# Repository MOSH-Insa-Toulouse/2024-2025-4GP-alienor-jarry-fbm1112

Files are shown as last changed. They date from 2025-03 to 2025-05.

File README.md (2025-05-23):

# 2024-2025-4GP - Projet Capteur low-tech Graphite - Aliénor Jarry et Bastien Maïs

## Sommaire :
- [Contexte](#contexte)
- [Livrables](#livrables)
- [Matériel nécessaire](#matériel-nécessaire)
- [1. Simulation électronique du capteur sous LTSpice](#1-simulation-électronique-du-capteur-sous-ltspice)
- [2. Design du PCB sous KiCad](#2-design-du-pcb-sous-kicad)
- [3. Réalisation du Shield](#3-réalisation-du-shield)
- [4. Code Arduino](#4-code-arduino)
- [5. Application Android APK sous MIT App Inventor](#5-application-android-apk-sous-mit-app-inventor)
- [6. Banc de test](#6-banc-de-test)
- [7. Datasheet du capteur](#7-datasheet-du-capteur)
- [Conclusion](#conclusion)
- [Contacts](#contacts)

## Contexte
Dans le cadre de l'UF "Du capteur au banc de test en open source hardware" se déroulant lors de notre 4ème année Génie Physique à l'INSA de Toulouse, nous avons développé un capteur à jauge de contrainte low-tech à base de crayon graphite. Ce projet repose sur le rapport scientifique "Pencil Drawn Strain Gauges and Chemiresistors on Paper", publié en 2014 par Cheng-Wei Lin*, Zhibo Zhao*, Jaemyung Kim & Jiaxing Huang.

Le capteur se compose uniquement d'un morceau de papier sur laquelle une trace de crayon à papier dépose une fine couche de graphite. Un dépôt de graphite sur du papier constitue un système granulaire, où des grains de tailles variables sont séparés par une distance appelée distance inter-grain. La conductance suit une loi exponentielle décroissante en fonction de la distance inter-grain, laquelle peut être modifiée en déformant le papier. Plus la distance inter-grain augmente, plus la conductance diminue. Dans ce cas, la résistance devient très élevée, car conductance et résistance sont inversement proportionnelles. Ainsi, la contrainte exercée sur le matériau peut être déterminée en mesurant simplement la résistance aux bornes du capteur.

L'objectif est de concevoir un dispositif permettant la mesure de déformation à partir d'un capteur low-tech, puis d'évaluer ses performances en le comparant à un capteur commercial.

## Livrables
- Un Shield PCB branchée sur une carte Arduino UNO, intégrant un capteur graphite, un amplificateur de transimpédance et un module Bluetooth. Idéalement, il incluerait également un écran OLED, un encodeur rotatif, un potentiomètre numérique (remplaçant la résistance R2 dans le circuit amplificateur), ainsi qu'un connecteur pour un servomoteur et un capteur de flexion (afin de comparer ses mesures avec celles du capteur en graphite).
- Un code Arduino garantissant la gestion de tous les composants et l'acquisition des mesures (mesures de contrainte, échanges via Bluetooth, affichage OLED, encodeur rotatif, potentiomètre numérique et servomoteur).
- Une application APK Android qui gère l'interface entre le PCB et le code Arduino. L'application doit au minimum afficher la valeur de la résistance de la jauge de contrainte ainsi que sa variation relative sur le smartphone.
- Un code Arduino dédié au banc de test pour la mesure de la jauge de contrainte.
- Une datasheet du capteur en graphite (incluant le circuit de transimpédance).

## Matériel nécessaire
Pour concevoir notre dispositif électronique, voici la liste des composants nécessaires :
- Des résistances : 1 de 1 kΩ, 1 de 10 kΩ, 2 de 100 kΩ pour l'amplificateur transimpédance. 1 de 47 kΩ pour le flex sensor (capteur commercial)
- Des condensateurs : 2 de 100 nF et 1 de 1 μF pour l'amplificateur transimpédance. 1 de 100 nF pour l'encodeur rotatif
- Un amplificateur opérationnel LTC1050
- Un potentiomère numérique MCP41050
- Une carte Arduino UNO
- Un module Bluetooth HC05
- Un écran OLED 128×64
- Un encodeur rotatif
- Un servomoteur
- Un flex sensor
- Un morceau de papier et crayon pour la fabrication du capteur graphite

## 1. Simulation électronique du capteur sous LTSpice

Notre capteur graphite présente une résistance variable de l’ordre du gigaohm (GΩ). Lorsque une tension de 5V est appliquée à ses bornes, un courant extrêmement faible est généré, de l’ordre de 100 nA en moyenne.

Un tel signal est difficilement exploitable sans amplification. Pour y remédier, nous avons utilisé un montage transimpédance basé sur un amplificateur opérationnel (AOP). Ce montage permet de convertir ce courant en une tension suffisamment élevée pour être lue par le convertisseur analogique-numérique (ADC) d’une carte Arduino UNO. 

**Nous avons simulé ce montage à l’aide du logiciel LTspice, voici notre schéma du circuit analogique** : 
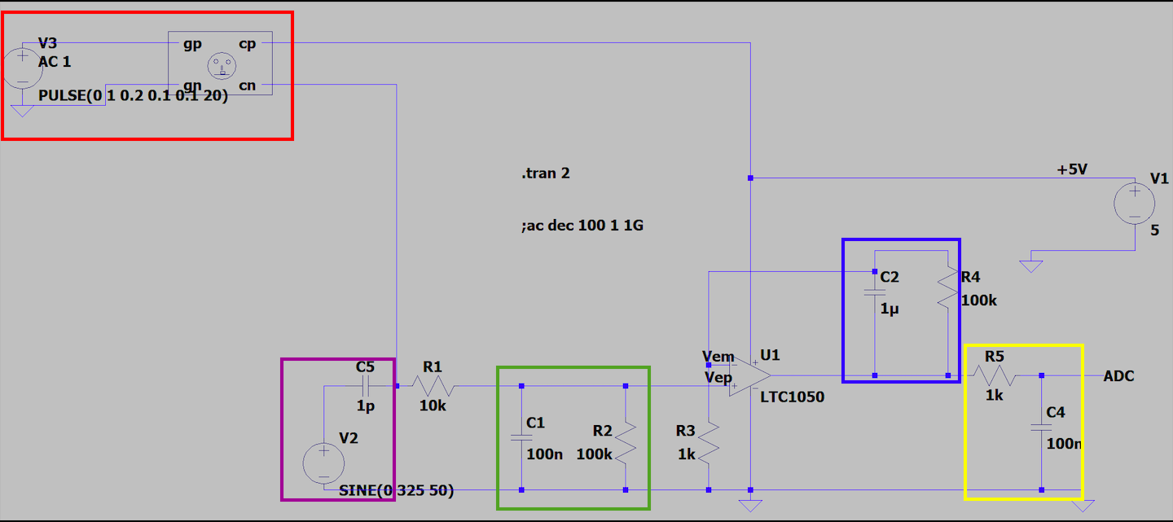
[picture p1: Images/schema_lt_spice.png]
Schéma LTSpice


Nous avons choisi l'AOP LTC1050 car il est adapté pour traiter de très faibles courants d'entrée. Son faible offset de tension assure une conversion précise du courant en tension.

**Deux éléments de simulation sont intégrés au circuit** :

- 🟥 Simulation du capteur  
- 🟪 Simulation du bruit

De plus, des filtres ont été ajoutés au montage afin d'atténuer les perturbations indésirables (par ex : bruits d'alimentation à 50 Hz) 

**Trois filtres assurant le traitement du signal** :

- 🟩 Filtre en entrée de l'AOP(R2, C1) :  
 C'est un filtre passe-bas passif de fréquence de coupure fc = 16 Hz. Il filtre les bruits en courant sur le signal d'entrée.

- 🟦Filtre couplé à l'AOP (R4, C2) :  
  C'est un filtre passe-bas actif avec fc = 1,6 Hz. Il filtre la composante du bruit à 50Hz du réseau électrique.

- 🟨 Filtre en sortie de l'AOP (R5, C4) :  
  C'est un filtre passe-bas passif avec fc = 1,6 kHz. Il élimine les parasites générés lors du traitement du signal.

De plus, la résistance R1 en entrée protège contre les décharges électrostatiques. Cette résistance en combinaison avec la capacité C5, forme un filtre pour atténuer les bruits de tension. 

**Voici la réponse de notre circuit afin de vérifier que le capteur est bien amplifié** :
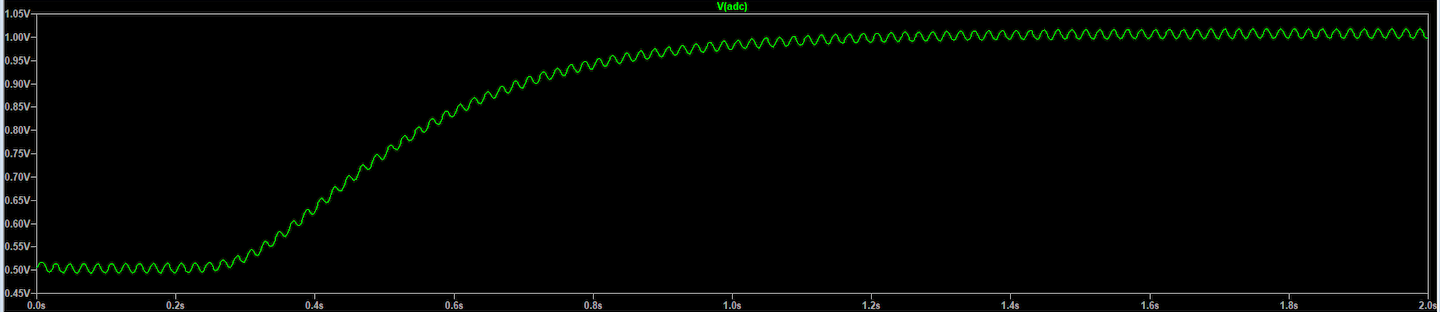
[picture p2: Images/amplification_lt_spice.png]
Réponse amplification LTSpice

Nous voyons que le signal est amplifié à 1V. Ainsi, l'Arduino UNO pourra le mesurer. 

**Réponse avec un courant alternatif pour vérifier que le bruit est bien filtré** :
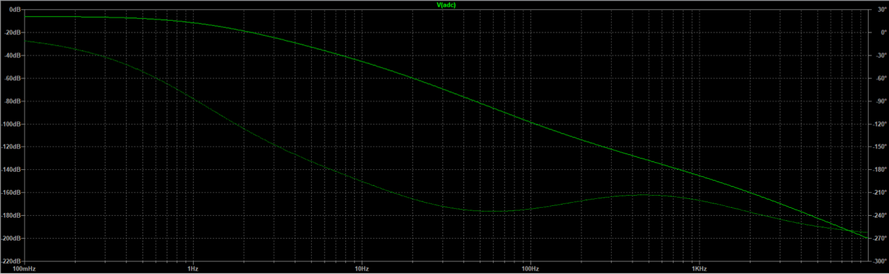
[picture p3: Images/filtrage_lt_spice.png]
Réponse filtrage LTSpice

Nous remarquons que le bruit est bien atténué à 50 Hz, d'environ 72 dB.

## 2. Design du PCB sous KiCad

Notre PCB a été conçue sur le logigiel Kicad (version 9).

Nous avons tout d'abord réalisé la schématique en reproduisant le circuit transimpédance (en enlevant la partie simulant le bruit). Nous avons  remplacé la résistance R3 par un potentiomètre digital. Cela nous permet d'ajuster le gain de notre AOP en fonctions de nos besoins. Également, nous avons créé les symboles des différents composants/modules intégrés. Ces modules assureront une mesure précise de notre capteur en graphite et permettra de comparer les résultats obtenus.

**Voici le schéma électrique de l'ensemble de notre montage** :
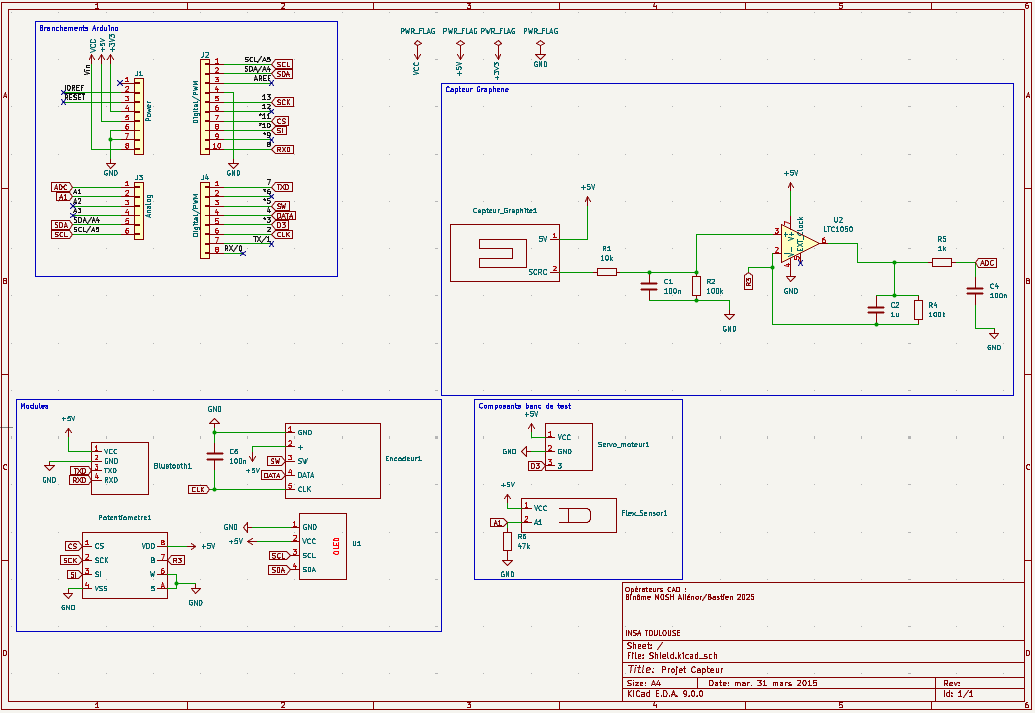
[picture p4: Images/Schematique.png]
Schematique


Ensuite, nous avons réalisé les empreintes de nos composants en prenant en compte leurs caractéristiques techniques : nombre de pins, espacement, dimensions, géométrie,...
afin de les placer sur notre PCB. 

Puis, nous sommes allés dans l'onglet "éditeur de PCB" sous Kicad pour designer notre circuit. Nous nous sommes appuyés sur un modèle de carte Arduino Uno. Nous avons ainsi placé nos différents composants, de manière à regouper les composants du circuit transmpédance. De plus les modules, et les composants du circuit transimpédance devaient être placés proches de leurs branchements Arduino respectifs. Nous sommes ensuite passés à la partie routage du circuit. Notre principale difficulté a été d’optimiser le placement des composants afin de limiter au maximum l’utilisation de vias, notamment pour les connexions au GND. Nous avons tout de même trois vias sur notre PCB. Pour garantir une bonne connexion entre toutes les broches GND des composants, nous avons mis en place un plan de masse.

**Voici le résultat final obtenu de notre routage** : 
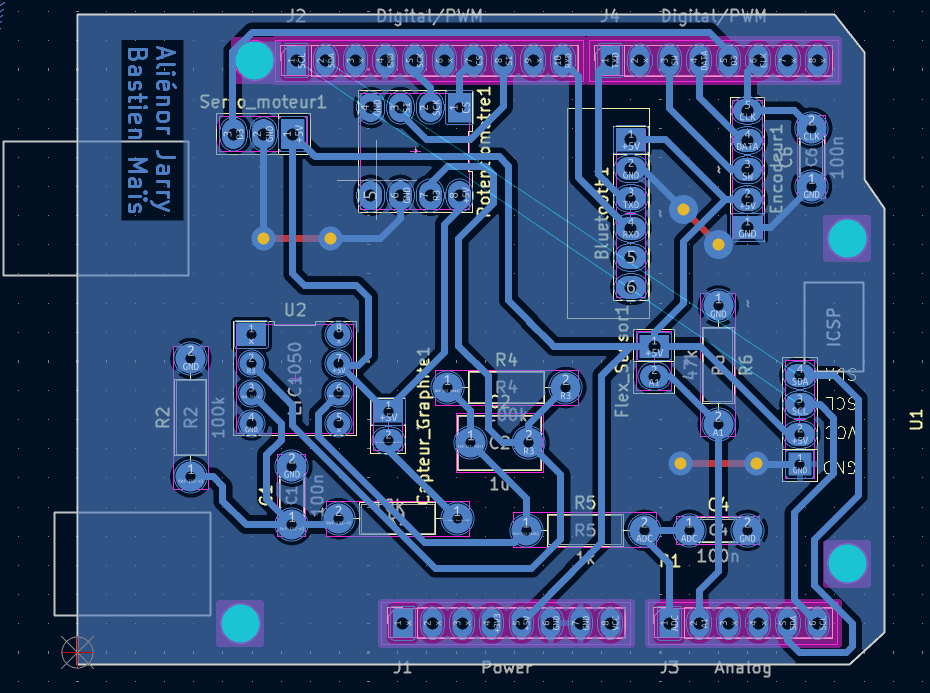
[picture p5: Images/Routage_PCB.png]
Routage_PCB


**Voici le rendu 3D de notre PCB, avec ses différents modules et composants intégrés**:
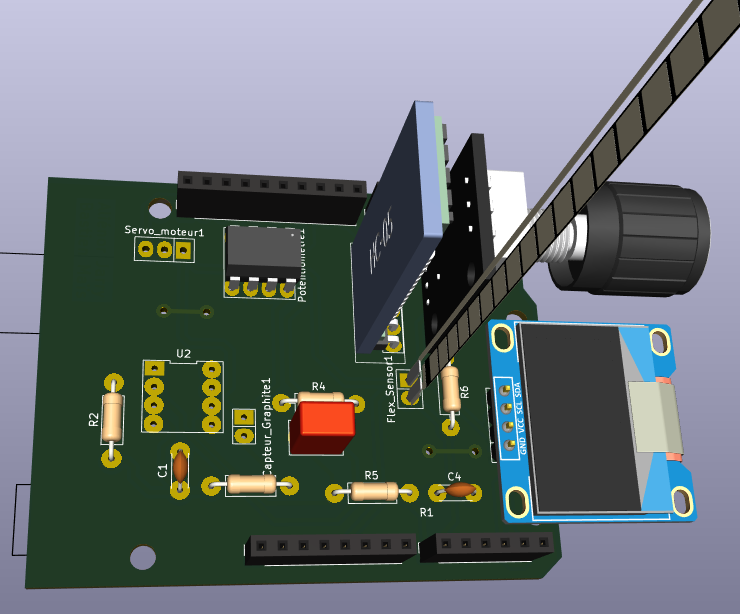
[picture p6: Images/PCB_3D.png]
PCB_3D


### **Erreurs réalisées** : 

Nous avons fait quelques erreurs concernant les empreintes de nos modules.

**Servomoteur** :
Nous avons inversé les broches GND et 5V. 

**Bluetooth HC-05** : 
L'empreinte de notre Bluetooth n'est pas correcte. Nous avions mis dans l'ordre la broche VCC, GND, TX, RX, ENABLE et STATE alors que la broche ENABLE est la première. Voici les broches correctes du Bluetooth :

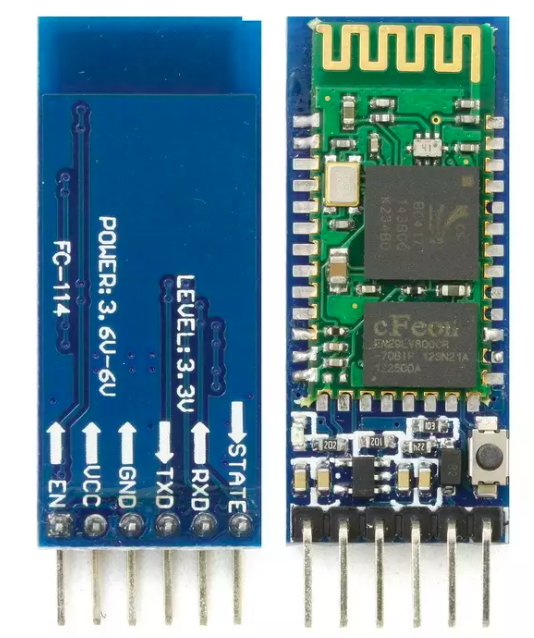
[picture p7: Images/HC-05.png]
HC-05


Un conseil serait de se baser sur la datasheet de chaques composant afin de réaliser les empreintes! De plus, il faut faire attention concerant les broches TX et RX du Bluetooth. La broche RX de la carte Arduino doit être raccordée à la broche TX du Bluetooth, et la broche TX du Arduino à la broche RX du Bluetooth.
Nous avons résolu le problème des pins Bluetooth en utilisant des connecteur mâles, femelles permettant de brancher correctement le Bluetooth.

## 3. Réalisation du Shield 

Une fois notre PCB finalisé sous KiCad, nous l’avons envoyé à Cathy afin qu’elle puisse vérifier que le PCB était conforme et prêt pour une impression correcte. Puis, nous avons généré le masque de gravure de notre PCB que Cathy s’est chargée d’imprimer. Ensuite, nous sommes allées avec Cathy au GEI afin de tirer notre PCB.

Nous n’avons pas pu manipuler directement, mais nous avons tout de même pu observer le processus de fabrication de la carte. Cathy a procédé ainsi :

1. Insolation UV de la plaque en époxy recouverte d'une fine couche de cuivre (destinée à recevoir le circuit imprimé) et d'une résine photosensible, à travers le masque, pour durcir la résine dans les zones exposées.
2. Développement : la plaque est plongée dans un révélateur pour éliminer la résine non exposée à la lumière UV, laissant ainsi un motif de résine durcie correspondant au circuit imprimé.
3. Gravure : La plaque est ensuite immergée dans un bain de perchlorure de fer, qui dissout le cuivre non protégé par la résine durcie, formant ainsi les pistes du circuit imprimé.
4. Nettoyage à l’acétone pour éliminer les résidus de résine restants après la gravure.

**Voici une photo du masque de gravure et une photo de notre PCB une fois imprimé** :
<p align="center">
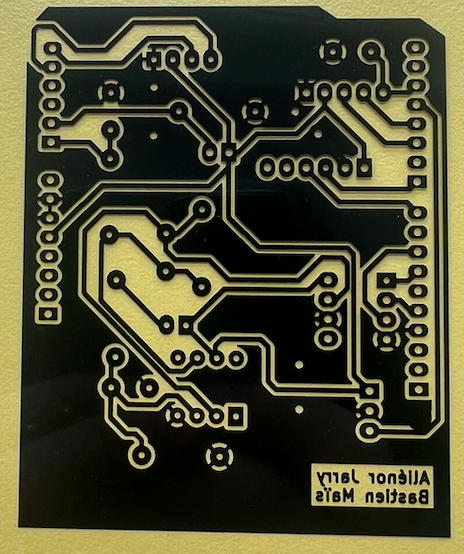
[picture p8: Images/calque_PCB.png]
calque_PCB
  
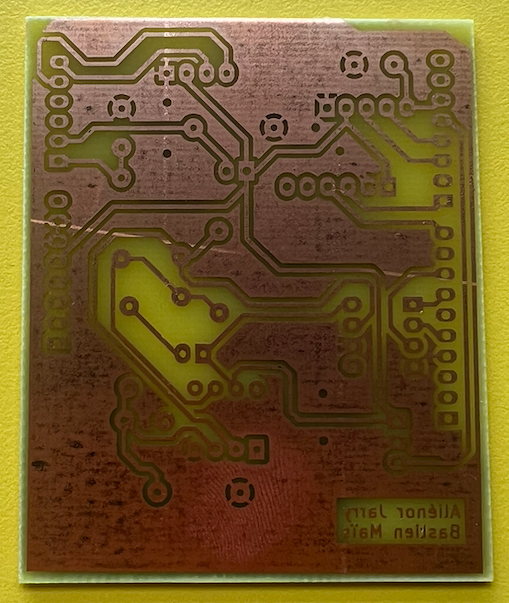
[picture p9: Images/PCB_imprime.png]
PCB_imprime
  
</p>

**Nous tenions à grandement remercier Cathy pour son aide tout au long du projet, et en particulier pour l'impression de notre PCB.**

### Assemblage du circuit :

Nous avons ensuite procédé au perçage de la plaquette pour permettre l'insertion des différents composants, en veillant à respecter la taille des trous. Un forêt plus petit était nécessaire pour les résistances et les condensateurs. Une fois le perçage effectué, nous avons soudé les composants sur le PCB. Il faut bien faire attention à souder uniquement sur les pastilles, sauf pour les pastilles GND où un débordement est moins problématique, car elles sont toutes reliées au plan de masse. Un excès de soudure sur les pastilles pourrait en effet créer des courts-circuits. De plus, nous avons dû ajouter un fil reliant la broche 5V du flex sensor au 5V du module Bluetooth, car une portion de cuivre sur la piste les reliant a été retirée accidentellement en tentant d’enlever un surplus de soudure.

**Voici une photo de l'assemblage de notre circuit (sans les modules) ainsi qu'une photo de nos soudures** :
<p align="center">
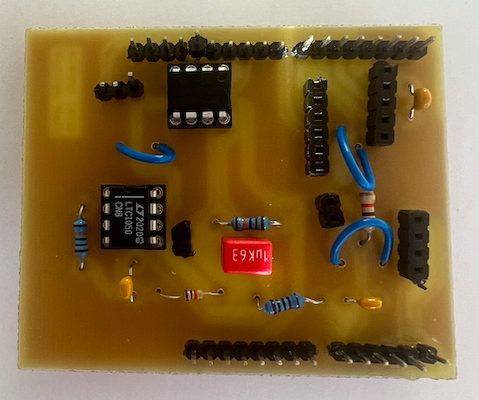
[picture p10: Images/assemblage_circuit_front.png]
assemblage_PCB
  
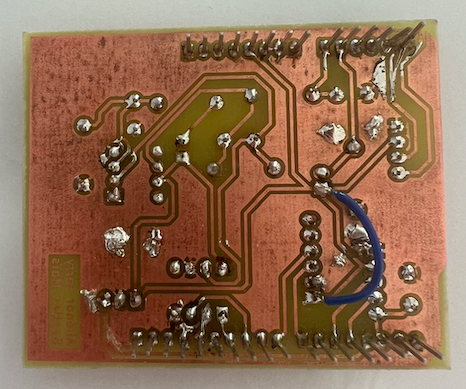
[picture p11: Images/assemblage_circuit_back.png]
soudure
  
</p>

## 4. Code Arduino 

Afin de réaliser le code arduino nous avons utilisé l'IDE 2.3.2.

Dans le cadre d'une utilisation d'application mobile nous avons donc utilisé un module bluetooth. Cela a ainsi nécessité d'inclure la librairie SoftwareSerial pour initier la communication entre l'application et le pcb via le module.

Pour une utilisation plus classique de notre montage, l'écran OLED permet l'affichage des valeurs issues des mesures de capteurs de la plaquette impliquant l'utilisation de la librairie Adafruit_SSD1306. Cette librairie est plus délicate à manipuler car gourmande en mémoire RAM. Pour pallier cet effet, il nous est impératif de limiter l'affichage au strict nécessaire afin de contrôler l'utilisation de la RAM et d'éviter d'éventuels disfonctionnements du programme.

Dans le dossier Arduino se trouve le programme complet strucuré qui permet de faire différents types de mesures selon le capteur utilisé (graphite ou flex sensor). Lors du lancement de l'Arduino, le programme effectue une calibration du potentiomètre digital selon la valeur mesurée par le capteur graphite pour ensuite afficher un menu déroulant que l'on peut balayer à l'aide de l'encodeur rotatif.

Le menu affiche 3 choix d'actions possibles : 

- Une mesure instantanée du capteur graphite toutes les 500ms
- Une mesure du flex sensor toutes les 500ms
- Une calibration du potentiomètre digital

<p align="center">
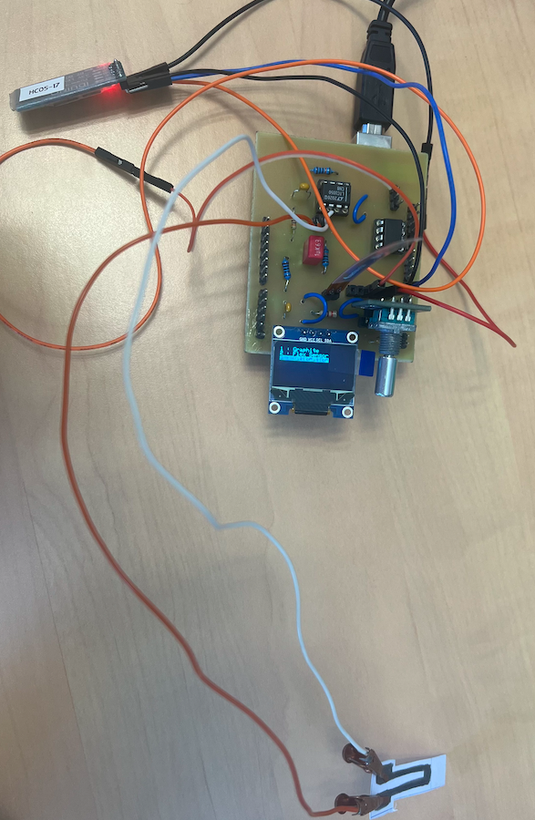
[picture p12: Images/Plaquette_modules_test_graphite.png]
Plaquette_modules
  
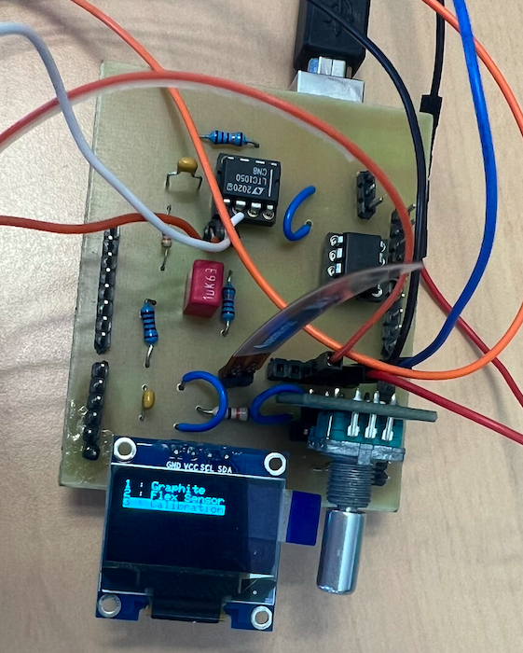
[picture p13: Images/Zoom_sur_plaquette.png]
zoom_plaquette
  
</p>

Pour sélectionner une action du menu, il suffit de tourner la molette et d'appuyer sur le bouton central de l'encodeur. Si l'on souhaite sortir d'une action du menu, nous tournons simplement la molette de l'encodeur.

Ainsi, on obtient la résistance du capteur graphite avec la formule suivante :

res

Et dans notre cas, notre résistance R3 est variable : elle est issue du réglage du potentiomètre à l'aide d'une méthode de dichotomie.

Finalement, nous n'avons pas utilisé le servomoteur comme module par manque de temps.

## 5. Application Android APK sous MIT App Inventor
Comme mentionné dans la partie précèdente, une application mobile a été réalisée sous MIT App Inventor.
L'application reçoit les données transmis par le module bluetooth HC-05 puis affiche la valeur reçue en Mohm pour le capteur graphite ou en ohms pour le flex sensor.

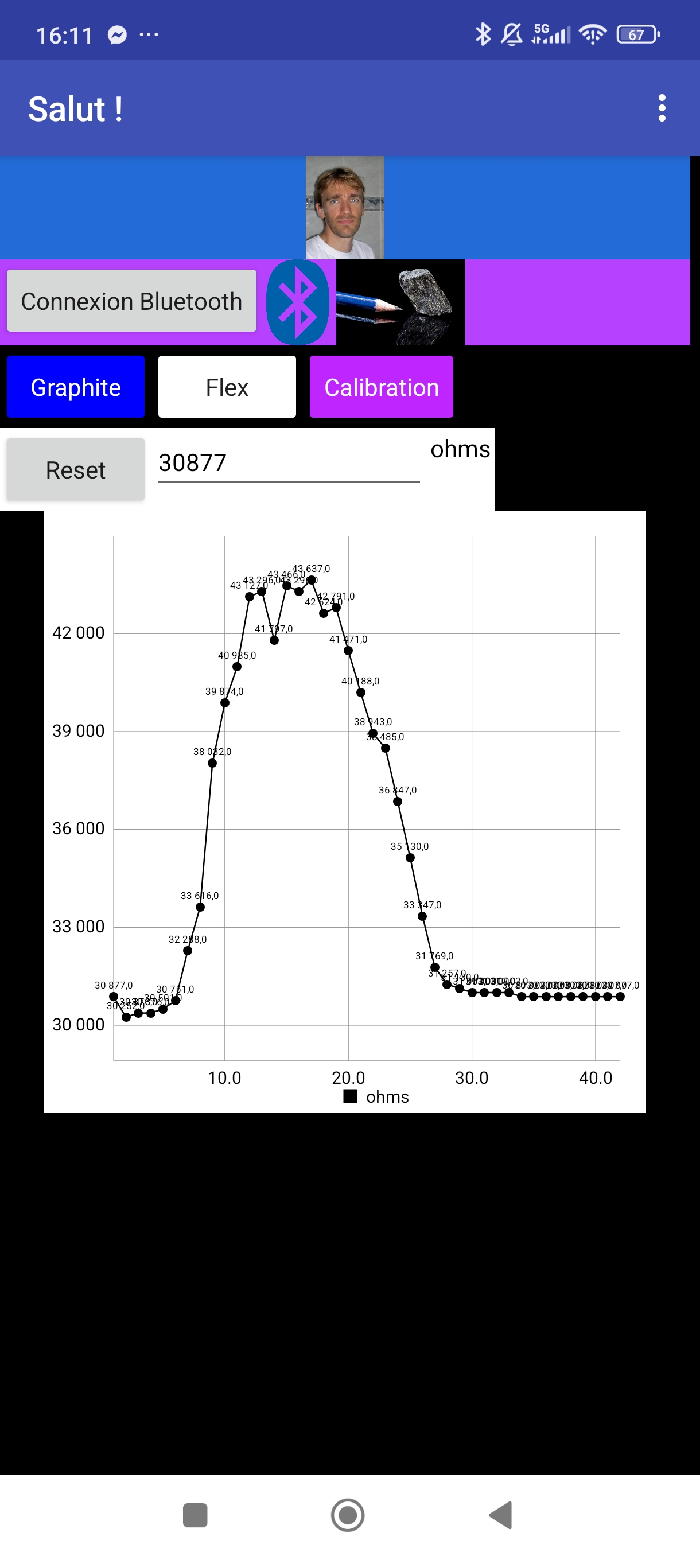
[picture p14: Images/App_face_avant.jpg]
face


<p align="center">
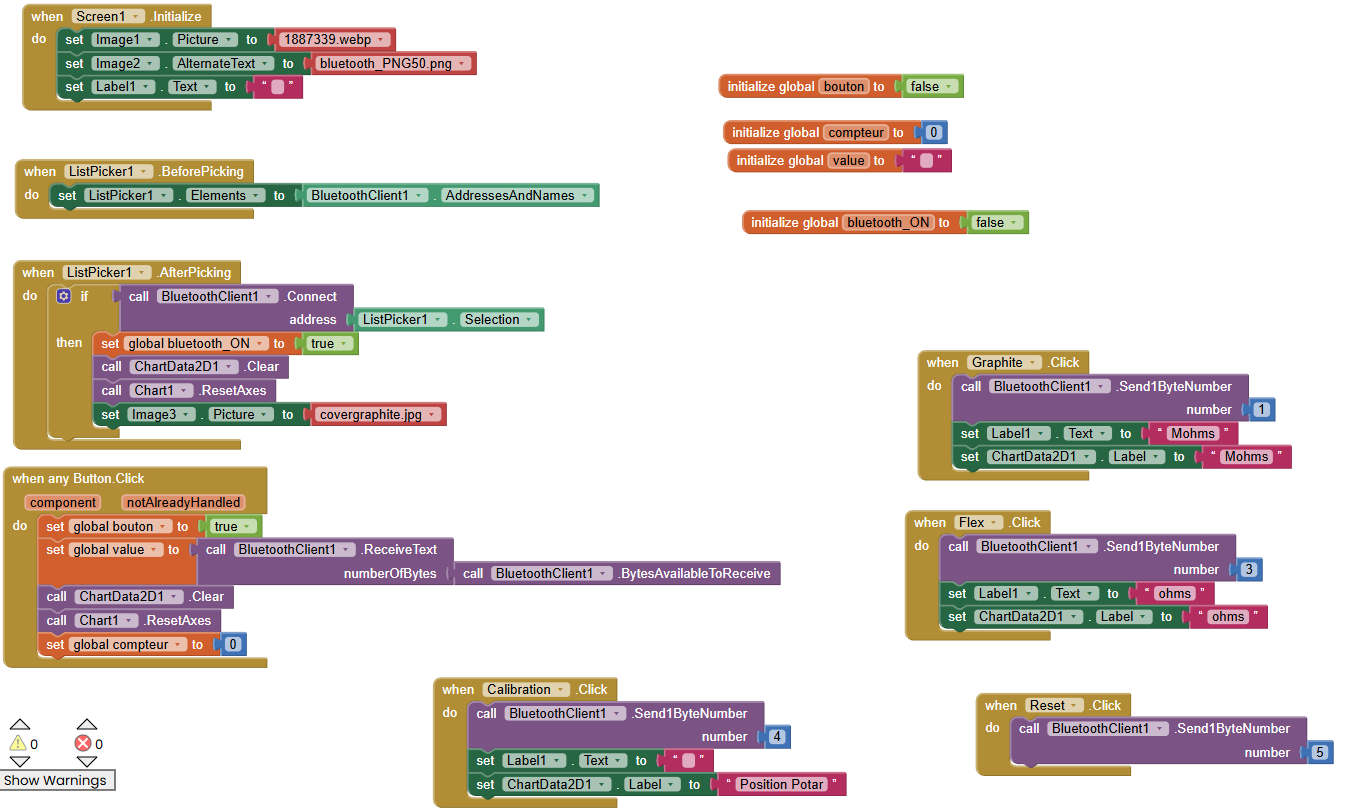
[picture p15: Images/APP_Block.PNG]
Block
  
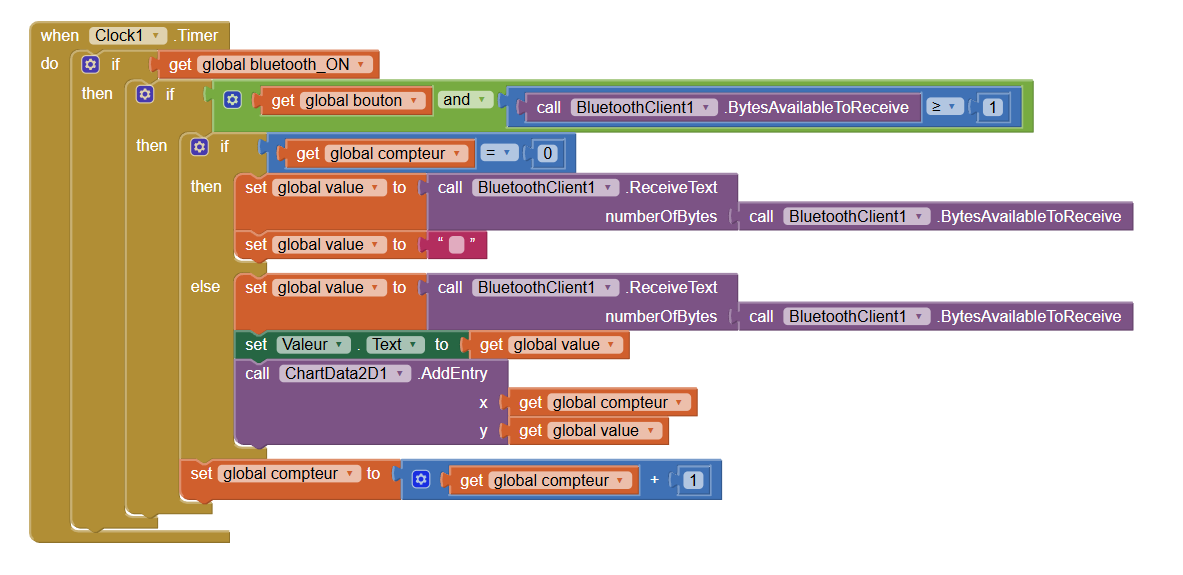
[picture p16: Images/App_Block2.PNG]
Block2
  
</p>

## 6. Banc de test
Pour spécifier notre capteur graphite et son montage transimpédance, nous avons utilisé le banc de test fabriqué par le binôme Maëlys et Arthur. Un grand merci à eux de nous avoir prêter leur banc de test. Ce banc de test comporte des demis-cercles avec des diamètres différents allant de 2cm à 4,5cm avec un rajout de 0,5cm entre chaque demi-cercle. Au total, il y a 6 demi-cercles. Ce banc de test comporte des encoches pour chaque demi-cercle qui permet d'insérer facilement le capteur. Une fois le capteur mis dans l'une de ses encoches, il est plus aisé d'appliquer une flexion ou une compression sur le capteur. La capteur se déforme en suivant la courbure du demi-cercle. Ainsi, nous appliquons une contrainte qui provoque une variation de la résistance du capteur. Nous allons mesurer cette contrainte en fonction de la déformation.

La variation relative de la résistance se définit par : ΔR/R0 (avec R0 la résistance initiale du capteur avant sa déformation et ΔR la variation de la résistance après et avant déformation). La déformation est : ε=e/D (avec e=0,2mm l'épaisseur du papier utilisé et D le diamètre du demi-cercle). Nous avons donc une déformation variant de 0.004 pour le plus grand demi-cerle à 0.01 pour le plus petit. Il faut faire attention à bien mettre les diamètres des demi-cercles en mm! 

**Voici le banc de test que nous avons utilisé :**

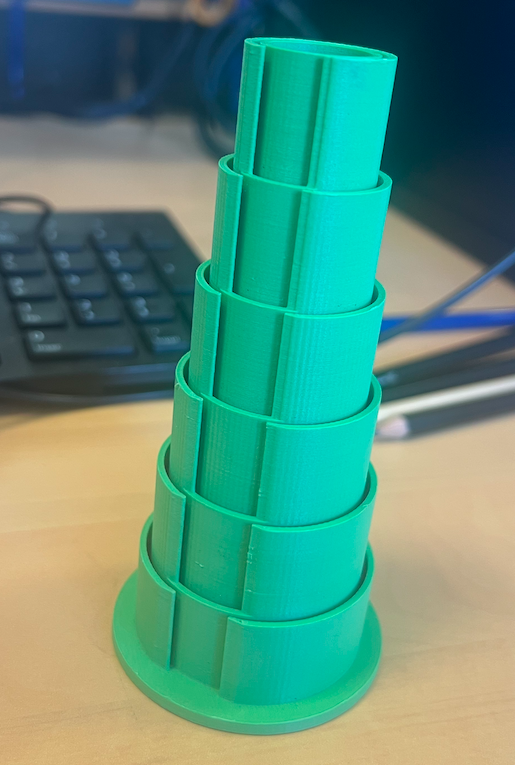
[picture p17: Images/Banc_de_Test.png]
Banc_de_Test


### Voici les courbes caractéristiques pour des crayons F, HB et B en flexion et en compression :
<p align="center">
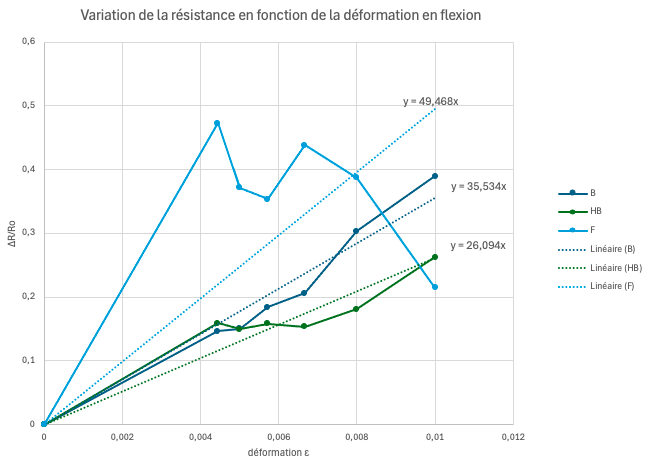
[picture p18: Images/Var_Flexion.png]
Var_Flexion
  
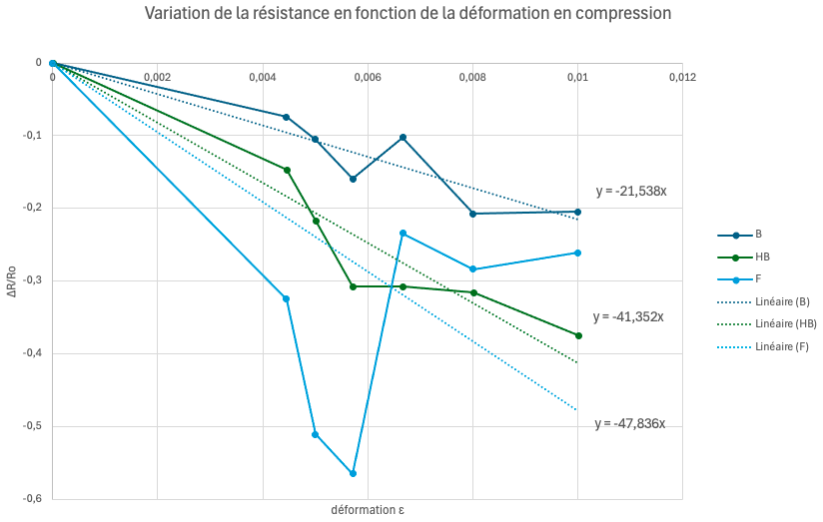
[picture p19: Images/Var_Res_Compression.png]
Var_Res_Compression
  
</p>

### Voici le graphe comparant le Flex Sensor et le capteur Graphite pour F, HB et B (en flexion) :
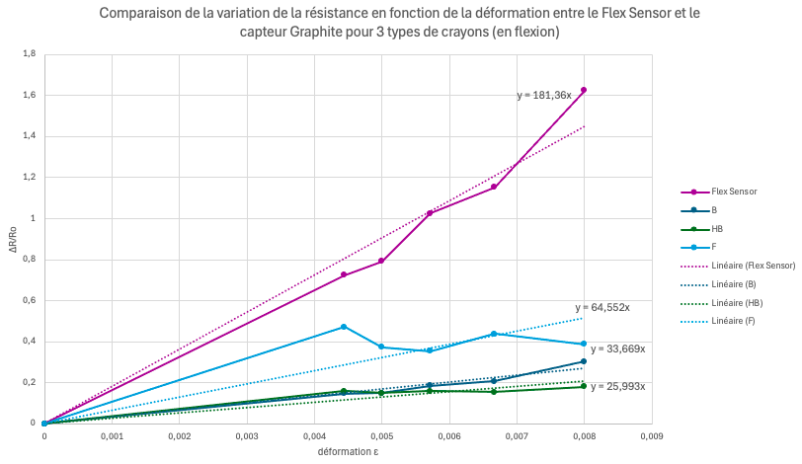
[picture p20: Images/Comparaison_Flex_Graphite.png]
Comparaison_Flex_Graphite


**Interprétation des courbes et comparaison avec la théorie :**

Nous remarquons que la résistance augmente lorsque nous mettons le capteur en flexion et que la résistance diminue lors de la compression de ce dernier. Ce phénomène est tout à fait attendu : en théorie, lorsqu’on soumet le capteur à une flexion, la monocouche de graphite déposée sur le papier s’étire, augmentant la distance entre les atomes de carbone. Cette augmentation de distance entraîne une hausse de la résistance du capteur. À l’inverse, en compression, les atomes de carbone se rapprochent, entraînant une diminution de la résistance.

Nous remarquons que les variations relatives ne sont pas les mêmes en fonction de la dureté du crayon utilisé. 
Plus le crayon est gras :  9H<...<3H<2H<H<F<HB<B<2B<3B<...9B, moins sa variation relative de résistance est élevée.
Dans notre cas, le crayon le plus dur et le crayon de type F et le plus gras est celui de type B. 
Cette théorie est vérifiée pour le cas des courbes en compression. Nous voyons bien que le type F a la variation relative la plus élevée et le B, la variation la moins élevée.
Pour le cas des courbes en flexion, la théorie n'est pas totalement vérifiée car le type F a bien la variation de résistance la plus élevée. Cependant, la variation relative la moins élevée est le type HB, alors que cela devrait être le type B. De plus, nous remarquons que nos courbes F, aussi bien en flexion qu'en compression présente un comportement non linéaire marqué. Ces courbes montrent plusieurs irrégularités et pics contrairement aux courbes de type B et HB qui sont plus linéaires.

Ces erreurs expérimentales peuvent être dues à une certaine instabilité dans la réponse du capteur, possiblement liée à une mauvaise homogénéité du dépôt de graphite. Elles peuvent également provenir de la qualité des crayons, des microfissures dans la couche conductrice (lors de la déformation mécanique) ou encore d'un contact imparfait entre le graphite et les pinces.

**Comparaison entre le capteur graphite et le capteur Flex sensor commercial :**

Enfin, nous avons comparé notre capteur graphite avec un flex sensor commercial. Ce flex sensor ne peut se déformer qu'en flexion (et non en compression). De plus, nous n'avons pas pu déformer le flex sensor à l'aide du plus petit demi-cercle de diamètre 20mm. En effet, les pins femelles du flex sensor sont directement fixés sur la PCB, ce qui  a limité la flexibilité du flex sensor. Pour avoir le même nombre de points sur le graphe que le flex sensor, nous n'avons donc pas pris en compte le plus petit demi-cercle pour le F, HB et B. Ceci explique la différence de pente pour le F, HB et B entre ce graphe et le premier graphe. 

Le flex sensor a une variation relative très élevée avec une pente a environ 180 comparé au capteur graphite, où la pente est de l'ordre de 20 à 60. Le capteur Flex est donc beaucoup plus sensible à la déformation. Sa réponse est plus régulière, linéaire et plus exploitable en conditions réelles.

## 7. Datasheet du capteur
Vous pouvez consulter la datasheet de notre capteur [ici](GSS250_Technical_Datasheet_Official.pdf).

## Conclusion
Malgré la composante low cost et de facilité d'usage de notre capteur, son nombre d'utilisation est très limité, qui diminue pour une déformation élevée.
En comparaison le Flex Sensor est plus sensible à la déformation avec un signal de réponse plus régulier est continu.

La mise en place du capteur graphite dans l'industrie amène aussi une contrainte de contrôle des épaisseurs du graphène sur le papier de manière homogène. En effet, les conditions d'essai sont non reproductibles car la quantité de graphite déposée au crayon à papier (à la main) variable, induisant ainsi une résistance variable à son tour. Les méthodes de dépot de couches actuels amène ainsi des couts suplémentaires

Tout de même, sa conception fait que l'on peut mesurer des tensions et des compressions avec un même produit.

Aussi, à l'issue du banc de test, nous avons retenu qu'il faudrait parvenir à un meilleur système de mise sous contraintes. Les manipulations manuelles requierent d'être suffisament alerte afin d'éviter des déformations additionelles au capteur limitant son utilisation. L'implémentaion de l'installation avec un servo moteur est une piste à suivre tout comme des pin plus adapté aux cables de connexion du capteur sur le pcb.

## Contacts
Aliénor Jarry : [ajarry@insa-toulouse.fr](mailto:ajarry@insa-toulouse.fr)  
Bastien Maïs : [mais@insa-toulouse.fr](mailto:mais@insa-toulouse.fr)

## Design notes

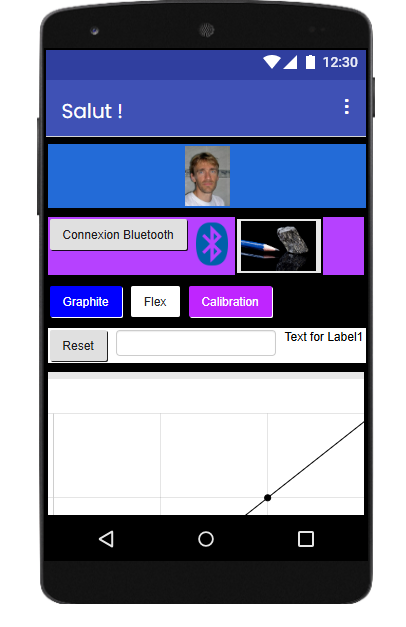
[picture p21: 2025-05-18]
Images/APP.PNG

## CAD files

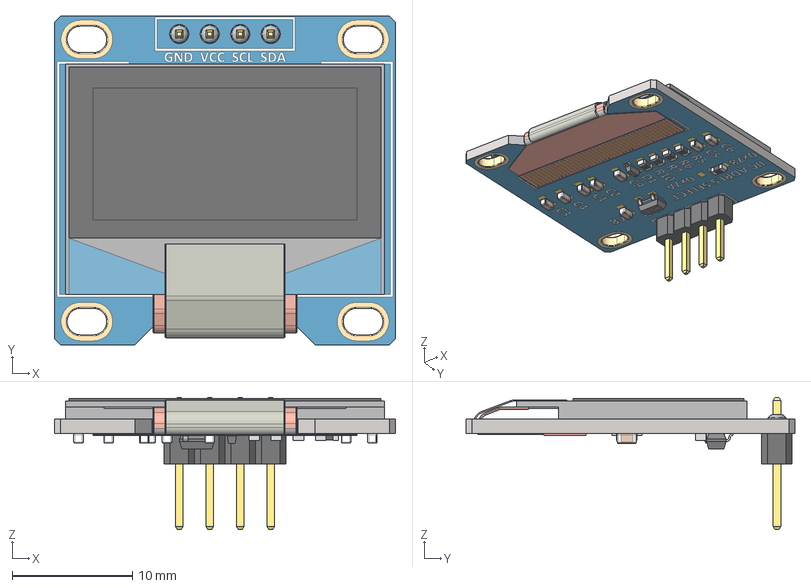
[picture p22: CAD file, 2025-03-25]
Kicad_Projet/Shield/model 3d/Pantalla OLED 0.96'' 128x64.stp
28.4 x 27.4 x 11.0 mm
SOT-23_TOR
RES_CR16_MTK_1 x 4
RES_CR16_MTK
SOD323F_DIO

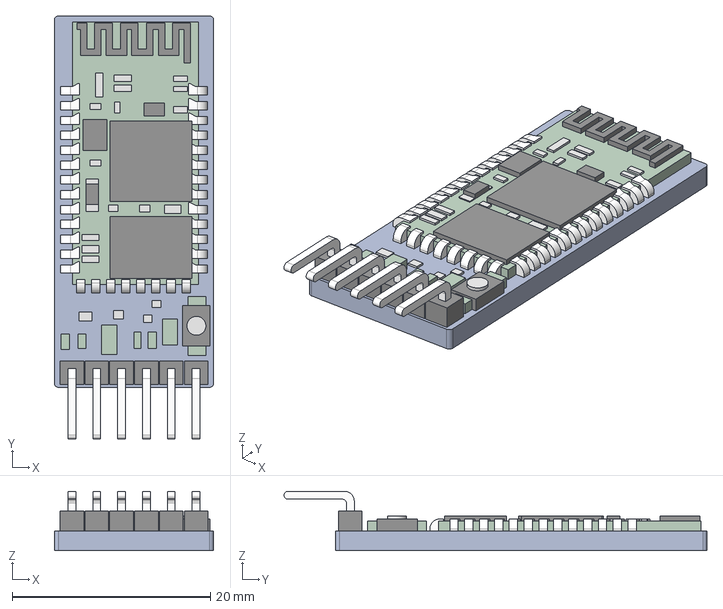
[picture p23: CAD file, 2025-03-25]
Kicad_Projet/Shield/model 3d/HC_05 Blue Tooth Module.stp
16.1 x 42.7 x 6.00 mm

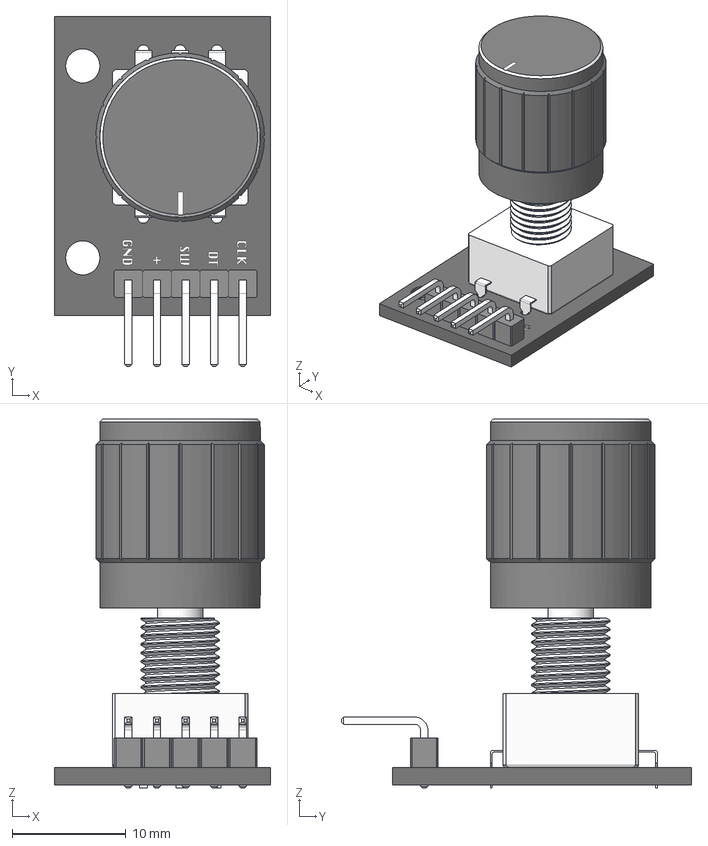
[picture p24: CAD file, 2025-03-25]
Kicad_Projet/Shield/model 3d/Rotary Encoder - KY-040.step
19.0 x 30.8 x 32.4 mm

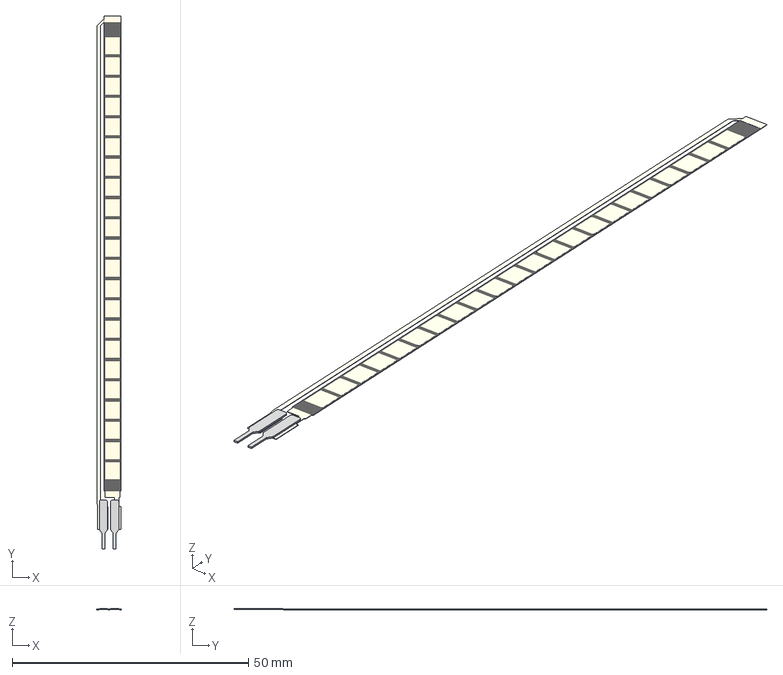
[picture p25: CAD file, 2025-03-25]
Kicad_Projet/Shield/model 3d/flex-sensor.stp
5.17 x 112.8 x 0.292 mm

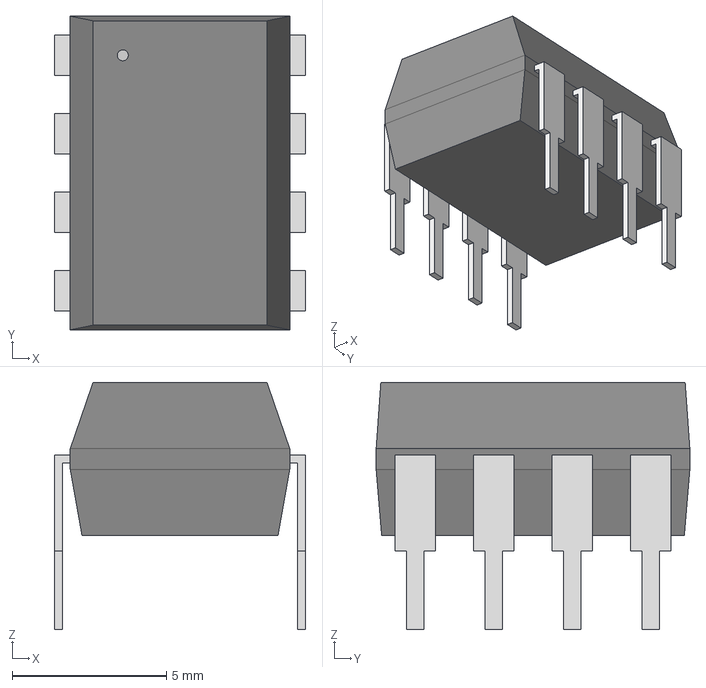
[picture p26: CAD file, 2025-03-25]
Kicad_Projet/Shield/model 3d/PDIP8_300MC_MCH.step
8.13 x 10.2 x 8.00 mm

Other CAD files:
Kicad_Projet/Shield/model 3d/pantalla/Pantalla OLED 0.96'' 128x64.stp

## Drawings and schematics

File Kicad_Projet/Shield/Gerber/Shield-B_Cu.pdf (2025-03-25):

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

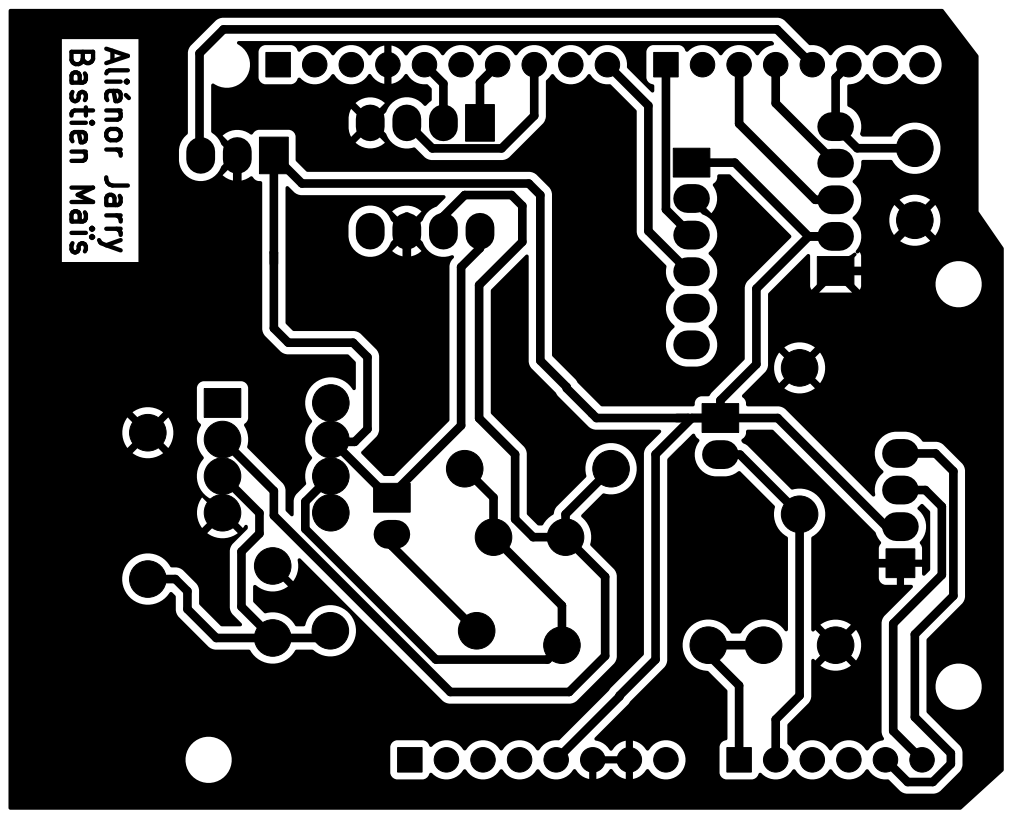
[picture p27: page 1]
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

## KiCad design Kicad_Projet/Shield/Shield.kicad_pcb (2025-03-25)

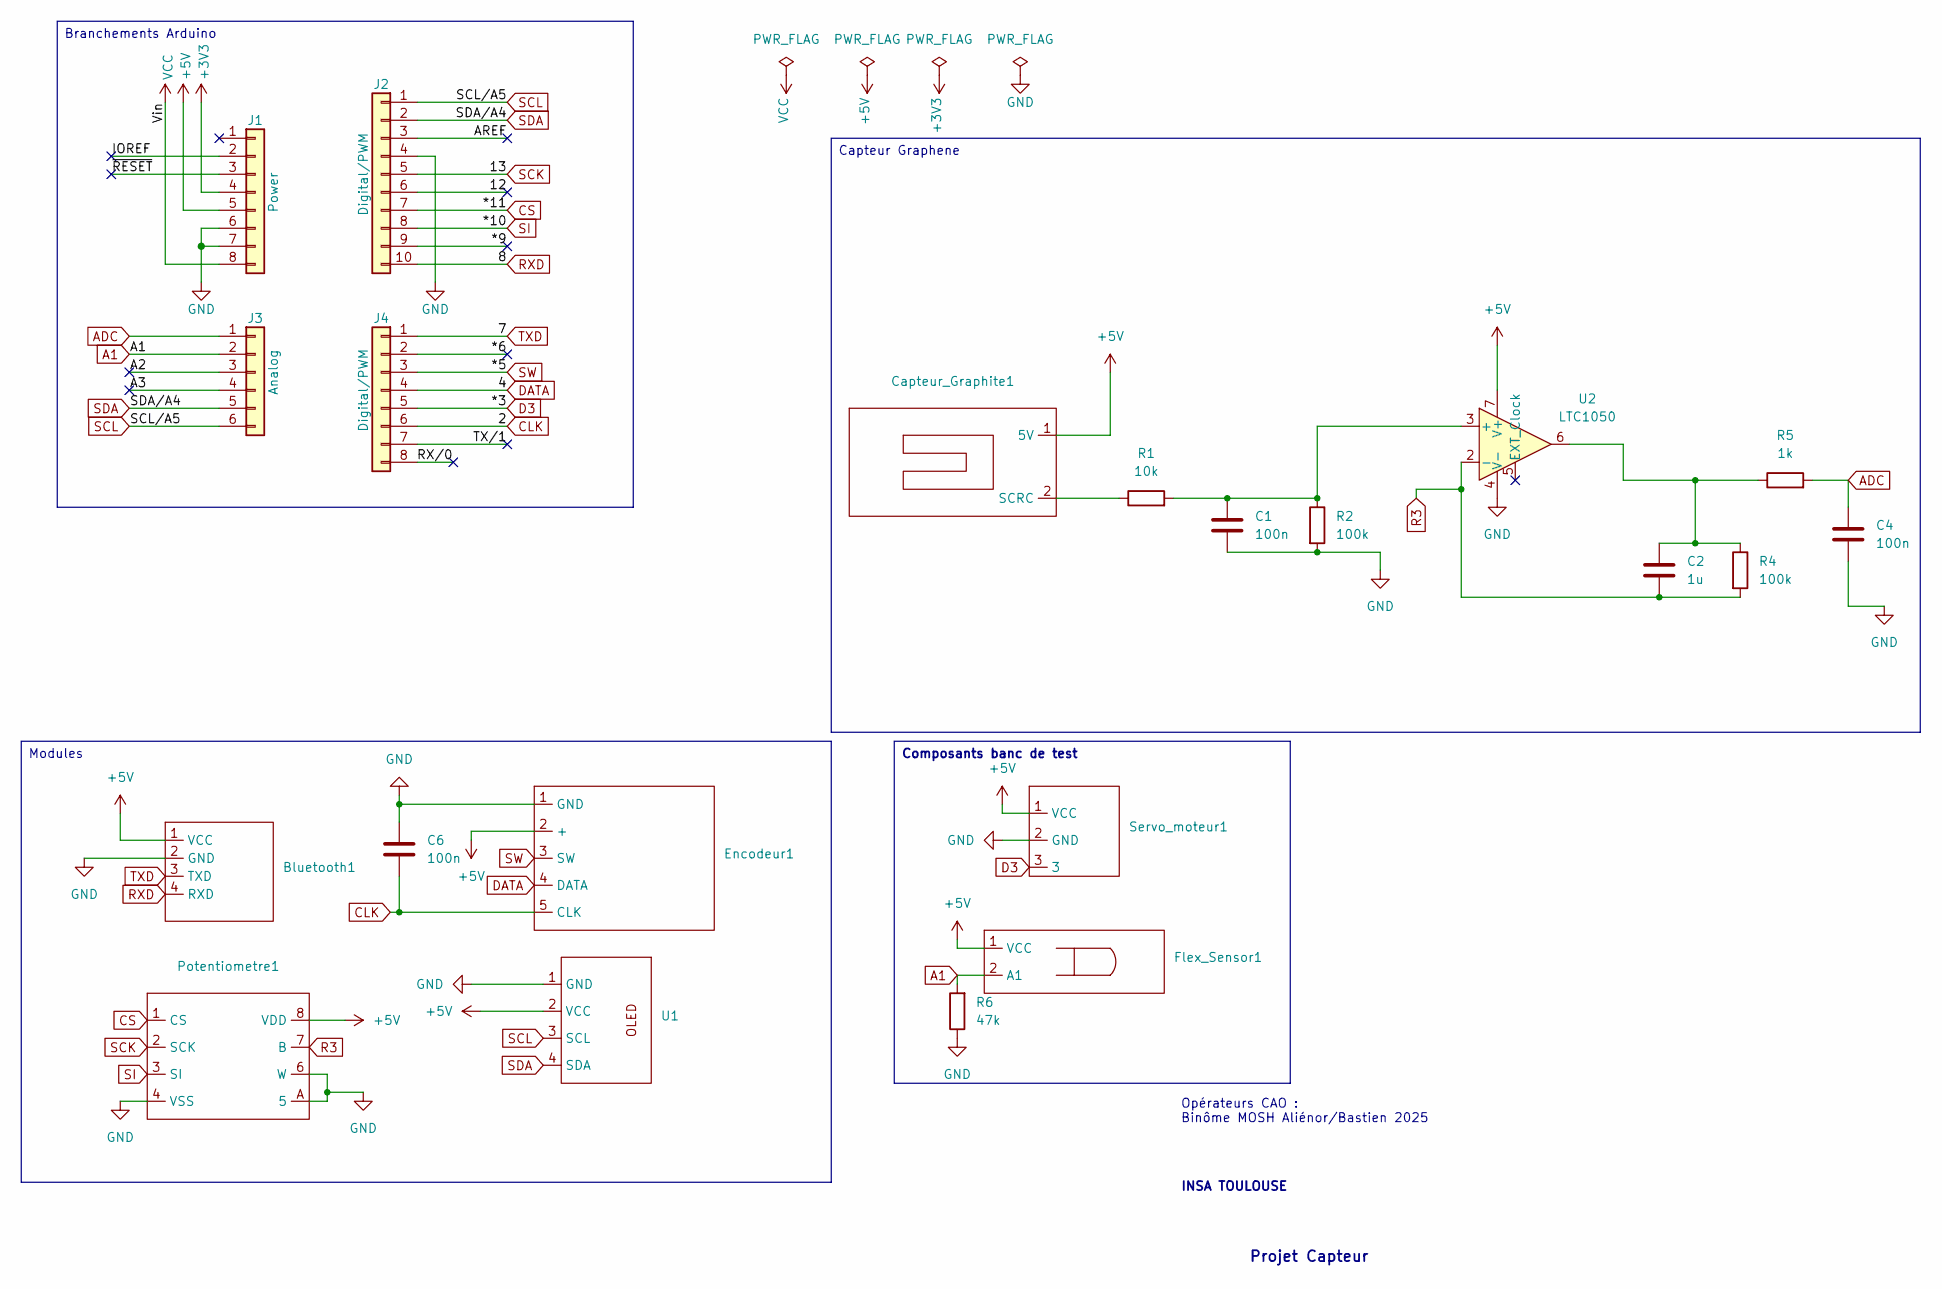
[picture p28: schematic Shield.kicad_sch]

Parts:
Bluetooth1: Bluetooth
C1, C4, C6: 100n; C_Disc_D4.3mm_W1.9mm_P5.00mm
C2: 1u; C_Rect_L7.0mm_W4.5mm_P5.00mm
Capteur_Graphite1: Capteur
Encodeur1: Encodeur
Flex_Sensor1: Flex_Sensor
J1: Power; PinSocket_1x08_P2.54mm_Vertical
J2: Digital/PWM; PinSocket_1x10_P2.54mm_Vertical
J3: Analog; PinSocket_1x06_P2.54mm_Vertical
J4: Digital/PWM; PinSocket_1x08_P2.54mm_Vertical
Potentiometre1: Potentiometre
R1: 10k; R_Axial_DIN0207_L6.3mm_D2.5mm_P10.16mm_Horizontal
R2, R4: 100k; R_Axial_DIN0207_L6.3mm_D2.5mm_P10.16mm_Horizontal
R5: 1k; R_Axial_DIN0207_L6.3mm_D2.5mm_P10.16mm_Horizontal
R6: 47k; R_Axial_DIN0207_L6.3mm_D2.5mm_P10.16mm_Horizontal
Servo_moteur1: Servo_Moteur
U1: OLED
U2: LTC1050; Ampli

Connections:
+3V3: J1.4
+5V: Bluetooth1.1 (VCC), Capteur_Graphite1.1 (5V), Encodeur1.2 (+), Flex_Sensor1.1 (VCC), J1.5, Potentiometre1.8 (VDD), Servo_moteur1.1 (VCC), U1.2 (VCC), U2.7 (V+)
/12: J2.6
/*6: J4.2
/*9: J2.9
/A2: J3.3
/A3: J3.4
/AREF: J2.3
/IOREF: J1.2
/RX/0: J4.8
/TX/1: J4.7
/~RESET: J1.3
A1: Flex_Sensor1.2 (A1), J3.2, R6.2
ADC: C4.1, J3.1, R5.2
CLK: C6.2, Encodeur1.5 (CLK), J4.6
CS: J2.7, Potentiometre1.1 (CS)
D3: J4.5, Servo_moteur1.3
DATA: Encodeur1.4 (DATA), J4.4
GND: Bluetooth1.2 (GND), C1.2, C4.2, C6.1, Encodeur1.1 (GND), J1.6, J1.7, J2.4, Potentiometre1.4 (VSS), Potentiometre1.6 (W), Potentiometre1.A (5), R2.2, R6.1, Servo_moteur1.2 (GND), U1.1 (GND), U2.4 (V-)
unnamed: C2.1, R4.1, R5.1, U2.6
unnamed: Capteur_Graphite1.2 (SCRC), R1.1
unnamed: C1.1, R1.2, R2.1, U2.3 (+)
R3: C2.2, Potentiometre1.7 (B), R4.2, U2.2 (-)
RXD: Bluetooth1.4 (RXD), J2.10
SCK: J2.5, Potentiometre1.2 (SCK)
SCL: J2.1, J3.6, U1.3 (SCL)
SDA: J2.2, J3.5, U1.4 (SDA)
SI: J2.8, Potentiometre1.3 (SI)
SW: Encodeur1.3 (SW), J4.3
TXD: Bluetooth1.3 (TXD), J4.1
VCC: J1.8

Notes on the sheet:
Opérateurs CAO : Binôme MOSH Aliénor/Bastien 2025
Projet Capteur
INSA TOULOUSE
Composants banc de test
Branchements Arduino
Modules
Capteur Graphene

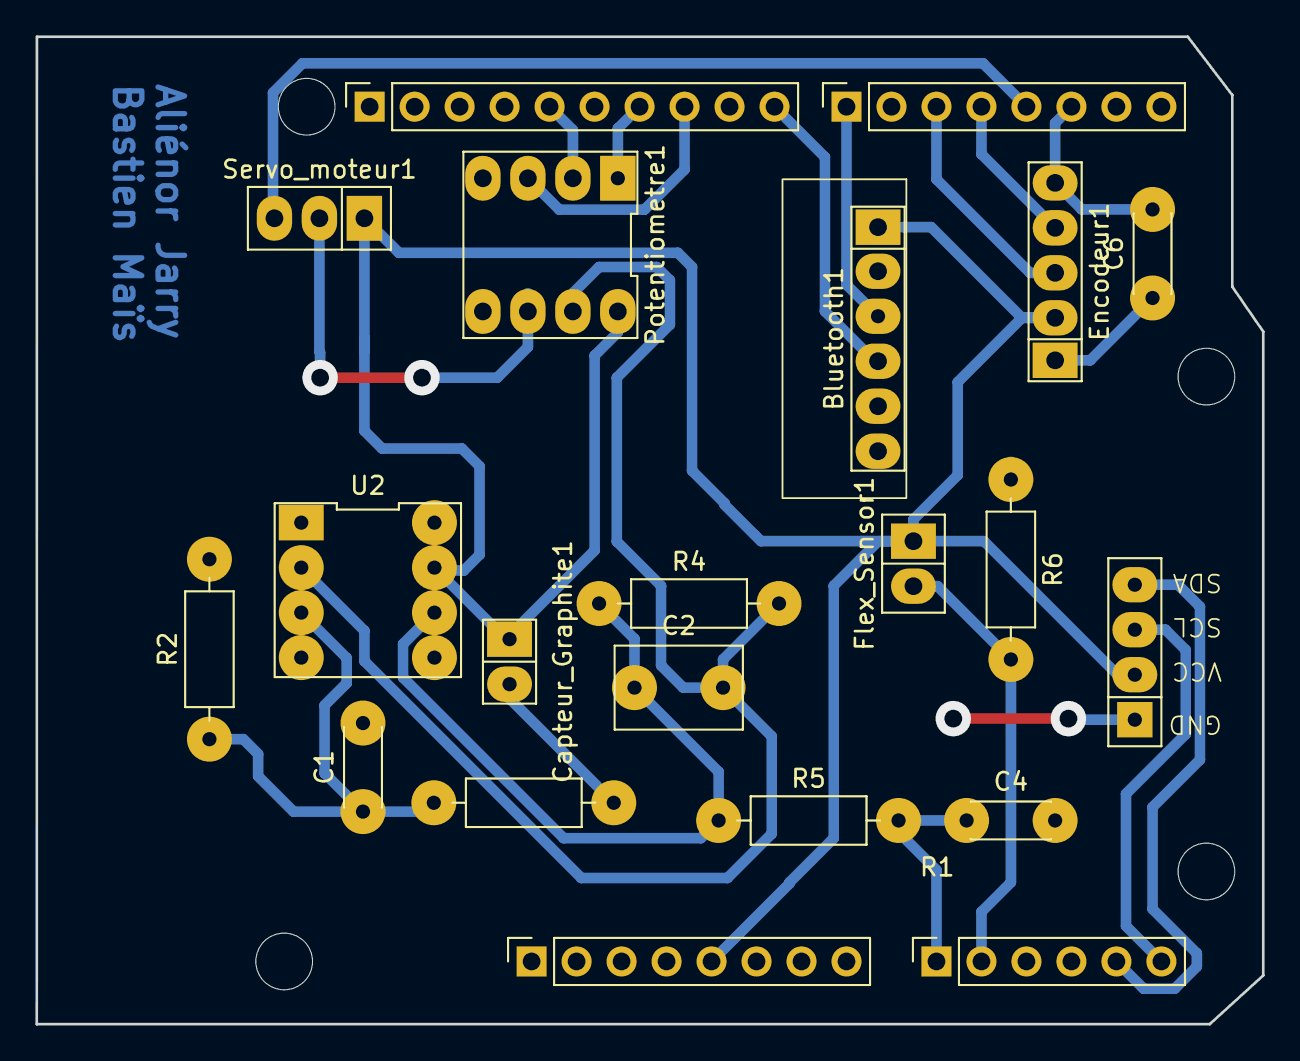
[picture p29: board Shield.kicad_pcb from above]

Board: 2 copper layers, 69.2 x 55.8 mm, 25 parts (0 on the bottom side), 19 nets.

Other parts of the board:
MH1, MH2, MH3, MH4: MountingHole_3.2mm

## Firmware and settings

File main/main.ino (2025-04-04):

//Bluetooth
#include <SoftwareSerial.h>
#define rxPin 8 // Correspondant à la broche tx du module bluetooth
#define txPin 7 // Correspondant à la broche Rx du module bluetooth
#define baudrate 9600 
SoftwareSerial mySerial(rxPin ,txPin); //Definition du software serial

//OLED ATTENTION, la librarie utilisée (d'origine) consomme énormement de mémoire RAM en buffer qui n'est pas affiché sur arduino (possible même si affiché seulement 40%)
// Si le programme ne lance rien, même pas le setup, le problème peut venir de là.
// On peut soit baisser le nombre de pixels dans l'écran, soit utiliser d'autre librairie moins gourmande facilement trouvable sur internet.
#include <Adafruit_SSD1306.h>
#define nombreDePixelsEnLargeur 128        // Taille de l'écran OLED, en pixel, au niveau de sa largeur
#define nombreDePixelsEnHauteur 64        // Taille de l'écran OLED, en pixel, au niveau de sa hauteur
#define brocheResetOLED         -1          // Reset de l'OLED partagé avec l'Arduino (d'où la valeur à -1, et non un numéro de pin)
#define adresseI2CecranOLED     0x3C        // Adresse de "mon" écran OLED sur le bus i2c (généralement égal à 0x3C ou 0x3D)
Adafruit_SSD1306 ecranOLED(nombreDePixelsEnLargeur, nombreDePixelsEnHauteur, &Wire, brocheResetOLED);  

// MESURE Pin pour mesure de la tension du capteur //////////
const int capteurgraphitePin = 0;  // Pin A0
float calibre = pow(10,-6); // pour avoir des Mohms
// Variables pour éviter le delay 
unsigned long previousMillis = 0;        // will store last time LED was updated
// Variable pour cadencer l'acquisition
const long interval = 500;           // interval at which to blink (milliseconds) for MesureINST

// MESURE FLEX SENSOR
const int flexPin = A1;      // Pin connected to voltage divider output
const float VCC = 5;      // voltage at Ardunio 5V line
const float R_DIV = 47000.0;  // resistor used to create a voltage divider
const float flatResistance = 30000.0; // resistance when flat
const float bendResistance = 1000.0;  // resistance at 90 deg

//BOUTONS
const int buttonPin[] = {4,5,6};  // Pin connected to button
// Variables will change:
bool buttonState[3]= {LOW,LOW,LOW};            // the current reading from the input pin
bool lastButtonState[3] = {LOW,LOW,LOW};  // the previous reading from the input pin
bool reading; // variable pour stocker la lecture de l'etat des boutons
//Variable debouncing
unsigned long lastDebounceTime = 0;  // the last time the output pin was toggled
unsigned long debounceDelay = 50;    // the debounce time; increase if the output flickers

// MENU ///////////////////////////
int Position = 1; // Position par défaut dans le menu
int OK = 0;        // Si le bouton central a été appuyé ou pas
String text1="1 : Graphite INST"; // Les différents menus
String text2="2 : Graphite MOY";
String text3="3 : Flex Sensor";
String text4="4 : Calibration";

//Android
bool OK_TEL=0; // Si un bouton sur téléphone a été cliqué.

// Digital Potentiometer
#include <SPI.h>
const byte csPin           = 11;      // MCP42100 chip select pin
const int  maxPositions    = 256;     // wiper can move from 0 to 255 = 256 Positions
const long rAB             = 52200;   // 50k pot resistance between terminals A and B, mais pour ajuster au multimètre, je mets 47500
const byte rWiper          = 125;     // 125 ohms pot wiper resistance
const byte pot0            = 0x11;    // pot0 addr // B 0001 0001
const byte pot0Shutdown    = 0x21;    // pot0 shutdown // B 0010 0001
long R2;                              // Valeur de R2 calculé en sortir du potentiomètre
int PotPos;                           // Valeur de la position du potentiomètre entre 0 et 255

// Permet de gérer le potentiomètre
void setPotWiper(int addr, int pos) {
  pos = constrain(pos, 0, 255);            // limit wiper setting to range of 0 to 255
  digitalWrite(csPin, LOW);                // select chip
  SPI.transfer(addr);                      // configure target pot with wiper Position
  SPI.transfer(pos);
  digitalWrite(csPin, HIGH);               // de-select chip

  R2 = ((rAB * pos) / maxPositions ) + rWiper; // Calcul de R2 (résistance entre wiper et B)
  Serial.print(F(" Resistance wiper to B terminal: "));
  Serial.print(R2);
}


void setup() {
    // Initialisation de l'écran OLED
  if(!ecranOLED.begin(SSD1306_SWITCHCAPVCC, adresseI2CecranOLED))
    while(1);   
  mySerial.begin(baudrate); // Initialiser le port bluetooth
  Serial.begin(baudrate); // Initialiser le port série


  pinMode(buttonPin[0], INPUT);     // Initialise les boutons
  pinMode(buttonPin[1], INPUT);
  pinMode(buttonPin[2], INPUT);
  digitalWrite(csPin, HIGH);        // chip select default to de-selected
  SPI.begin();
  delay(5000);
  PotPos=Calibration();             // Calibration du potentiomètre en fonction du capteur
  // setPotWiper(pot0,int(5));
  // R2=1144;
  }
  
void loop() {
  ChoixMenu(); // Affiche le menu et ses choix en boucle
}

// Permet de se balader dans les 4 menus différents
//MENU 1 : MesureINST : Mesure du capteur graphite toutes les 700ms~~
//MENU 2 : MesureMoyenne : Mesure du capteur graphite en faisant 50 mesures sur 2500ms
//MENU 3 : MesureINST : Mesure du capteur flex sensor
//MENU 4 : Calibration : Calibration du potentiomètre en fonction du capteur
void ChoixMenu(){
  // // MENU
  unsigned long currentMillis = millis ();
  if (currentMillis - previousMillis >= 500) 
  {
    previousMillis = currentMillis;
    ecranOLED.clearDisplay();                                   // Effaçage de l'intégralité du buffer
    ecranOLED.setTextSize(1);                           // Taille du texte
    ecranOLED.setCursor(0, 0);                          // Placement du texte
    ecranOLED.setTextColor(SSD1306_WHITE, SSD1306_BLACK);   // Couleur du texte, et couleur du fond
    //setPotWiper(pot0,7);
    CheckBoutons();   // Fonction primordiale : vérifie si les boutons physiques ne sont pas appuyé et ajuste la variable position, OK et OK_TEL (si un bouton sur tél n'est pas cliqué)
    if(Position==1)                       // Si nous sommes en position 1, affiche le texte correspondant (effet de surbrillance)
    {
      ecranOLED.setTextColor(SSD1306_BLACK, SSD1306_WHITE);
      ecranOLED.println(text1);
      ecranOLED.setTextColor(SSD1306_WHITE, SSD1306_BLACK);
      ecranOLED.println(text2);
      ecranOLED.println(text3);
      ecranOLED.println(text4);
      ecranOLED.display();                            // Transfert le buffer à l'écran
      if(OK_TEL==1) // Si un bouton sur téléphone est cliqué
      {
        OK_TEL=0; // Remet à 0
        MesureINST(); 
      }
      else if(OK==1) // Si le bouton central est cliqué
      {
        OK=0;     // Remet à 0
        MesureINST();
      }
    }
    else if (Position==2)// Si nous sommes en position 2, affiche le texte correspondant (effet de surbrillance)
    {
      ecranOLED.println(text1);
      ecranOLED.setTextColor(SSD1306_BLACK, SSD1306_WHITE);   // Couleur du texte, et couleur du fond
      ecranOLED.println(text2);
      ecranOLED.setTextColor(SSD1306_WHITE, SSD1306_BLACK);   // Couleur du texte, et couleur du fond
      ecranOLED.println(text3);
      ecranOLED.println(text4);
      ecranOLED.display();                            // Transfert le buffer à l'écran
       if(OK_TEL==1)
      {
        OK_TEL=0;
        MesureMoyenne();
      }
      else if(OK==1)
      {
        OK=0;
        MesureMoyenne();
      }
    }
    else if (Position==3)// Si nous sommes en position 3, affiche le texte correspondant (effet de surbrillance)
    {
      ecranOLED.println(text1);
      ecranOLED.println(text2);
      ecranOLED.setTextColor(SSD1306_BLACK, SSD1306_WHITE);
      ecranOLED.println(text3);
      ecranOLED.setTextColor(SSD1306_WHITE, SSD1306_BLACK); 
      ecranOLED.println(text4);
      ecranOLED.display();                            // Transfert le buffer à l'écran
       if(OK_TEL==1)
      {
        OK_TEL=0;
        FlexSensor();
      }
      else if(OK==1)
      {
        OK=0;
        FlexSensor();
      }
    }
    else if (Position==4)// Si nous sommes en position 4, affiche le texte correspondant (effet de surbrillance)
    {
      ecranOLED.println(text1);
      ecranOLED.println(text2);
      ecranOLED.println(text3);
      ecranOLED.setTextColor(SSD1306_BLACK, SSD1306_WHITE); 
      ecranOLED.println(text4);
      ecranOLED.display();
      if(OK_TEL==1)
      {
        OK_TEL=0;
        PotPos=Calibration();
      }
      if(OK==1)
      {
        OK=0;
        PotPos=Calibration();
      }    
    }
  }
}


// Vérifie si un bouton a été appuyé
void CheckBoutons()
{
  for (int i = 0; i < 3; i++) {
    reading = digitalRead(buttonPin[i]);

    // check to see if you just pressed the button
    // (i.e. the input went from LOW to HIGH), and you've waited long enough
    // since the last press to ignore any noise:
    // If the switch changed, due to noise or pressing:
    if (reading != lastButtonState[i]) {
      // reset the debouncing timer
      lastDebounceTime = millis();
    }

    if ((millis() - lastDebounceTime) > debounceDelay) {
      // whatever the reading is at, it's been there for longer than the debounce
      // delay, so take it as the actual current state:
      buttonState[i] = reading;
    }
    // save the reading. Next time through the loop, it'll be the lastButtonState:
    lastButtonState[i] = reading;
  }
  if(buttonState[0]==HIGH && Position < 4){ // Permet de descendre dans les menus sauf si en position 4
    Position++;
    buttonState[0]=LOW;}
  else if(buttonState[0]==HIGH && Position == 4){ // Si en position 4 et que l'utilisateur veut descendre, cela le fait remonter en position 1
    Position=1;
    buttonState[0]=LOW;
  }
  if(buttonState[1]==HIGH){ // si bouton central appuyé, alors cela correspond à une validation
    OK=1;
    buttonState[1]=LOW;
    }
  if(buttonState[2]==HIGH && Position > 1){ // Permet de monter dans les menus sauf si en position 1
    Position--;
    buttonState[2]=LOW;
    }
  else if(buttonState[2]==HIGH && Position == 1){// Si en position 1 et que l'utilisateur veut monter, cela le fait descendre en position 4
    Position=4;
    buttonState[2]=LOW;
  }
    if(mySerial.available()>0){ // Lis ce qui a été envoyé sur le module Bluetooth si nécessaire
    switch (mySerial.read()) {
    case 1: // si arduino reçois le chiffre 1 alors
      Position=1;
      //OK=1;
      OK_TEL=1;
      Serial.println(1);
      break;
    case 2: // si arduino reçois le chiffre 2 alors
      Position=2;
      //OK=1;
      OK_TEL=1;
      Serial.println(2);
      break;
    case 3: // si arduino reçois le chiffre 3 alors
      Position=3;
      //OK=1;
      OK_TEL=1;
      Serial.println(3);
      break;
    case 4: // si arduino reçois le chiffre 4 alors 
      Position=4;
      //OK=1;
      OK_TEL=1;
      Serial.println(4);
      break;
    }                   // wait for a second
  }
}


//Amelioration: faire une fonction de tout ce qui est affichage répété dans les 3 fonctions suivantes
// Permet de mesurer toutes les 500ms la valeur du capteur graphite
void MesureINST()
{
  float R3=100000;
  int Vcc=5;
  float R1=100000;
  int R5=10000;
  float Vadc=0;
  float Res=-1;
  // Affiche l'affichage de mesureINST avant les mesures réelles, comme cela, l'utilisateur peut arreter d'appuyer sur le bouton OK et cela évite de le faire sortir du programme
  ecranOLED.clearDisplay();                                   // Effaçage de l'intégralité du buffer
  ecranOLED.setTextSize(1);                   // Taille des caractères (1:1, puis 2:1, puis 3:1)
  ecranOLED.setCursor(0, 0);
  ecranOLED.setTextColor(SSD1306_WHITE, SSD1306_BLACK);   // Couleur du texte, et couleur du fond
  ecranOLED.println(F("Mesure instantannee : "));
  ecranOLED.display();    
  delay(1000);
  do
  {    
    // MESURE
    unsigned long currentMillis = millis();
    if (currentMillis - previousMillis >= interval) {
      previousMillis = currentMillis;
      Vadc = analogRead(capteurgraphitePin)*5.0/1024.0; // Valeur lu en voltage sortant du capteur
      Res=(R1*(1+R3/R2)*Vcc/Vadc-R1-R5)*calibre; // Calcul de la résistance
      Serial.print("Vadc = ");
      Serial.println(Vadc*1024/5);
      DisplayAndTransmitter(Res,1); // Transmet la donnée à afficher à l'ordi, à l'écran et au bluetooth
      CheckBoutons();
      }
  }while(!(OK == 1 || OK_TEL == 1)); // Tant que le bouton OK n'est pas appuyé, continue
  //Position=1;
  OK=0;
  //OK_TEL=0;
  //Permet de donner l'impression à l'utilisateur qu'il est sorti de l'écran MesureINST
  ecranOLED.clearDisplay();                                   // Effaçage de l'intégralité du buffer
  ecranOLED.setCursor(0, 0);
  ecranOLED.setTextSize(1);                 
  ecranOLED.setTextColor(SSD1306_BLACK, SSD1306_WHITE);   // Couleur du texte, et couleur du fond
  ecranOLED.println(text1);
  ecranOLED.setTextColor(SSD1306_WHITE, SSD1306_BLACK);   // Couleur du texte, et couleur du fond
  ecranOLED.println(text2);
  ecranOLED.println(text3);
  ecranOLED.println(text4);
  ecranOLED.display();    
  delay(1000);
 
} 

//Mesure du capteur graphite sur 50 mesures en 2500ms, forme similaire à MesureINST
void MesureMoyenne(){
  float R3=100000;
  int Vcc=5;
  float R1=100000;
  int R5=10000;
  float Vadc=0;
  float Res=-1;
  ecranOLED.clearDisplay();                                   // Effaçage de l'intégralité du buffer
  ecranOLED.setTextSize(1);                   // Taille des caractères (1:1, puis 2:1, puis 3:1)
  ecranOLED.setCursor(0, 0);
  ecranOLED.setTextColor(SSD1306_WHITE, SSD1306_BLACK);   // Couleur du texte, et couleur du fond
  ecranOLED.println(F("Mesure moyennee :"));
  ecranOLED.display();    
  delay(1000);
  do
  { 
    float moyenne=0;  
    for (int i = 0; i < 50; i++) {
      moyenne=moyenne+analogRead(capteurgraphitePin); 
      CheckBoutons();
      delay(50);
    }
    moyenne=moyenne*5/(50*1024); // Fais la moyenne sur les 50 mesures
    Res=(R1*(1+R3/R2)*Vcc/moyenne-R1-R5)*calibre; // Calcul de la résistance à partir de la valeur lue moyenne, possible de faire la moyenne des résistance calculées
    Res=(R1*(1+R3/R2)*Vcc/Vadc-R1-R5)*calibre; // Calcul de la résistance

    //Serial.print(F("Mesure moyennee :"));
    //Serial.println(Res);
    DisplayAndTransmitter(Res,2); // Transmet la donnée à afficher à l'ordi, à l'écran et au bluetooth
  }while(!(OK == 1 || OK_TEL == 1));
  //Position=2;
  OK=0;
  //OK_TEL=0;
  ecranOLED.clearDisplay();                                   // Effaçage de l'intégralité du buffer
  ecranOLED.setCursor(0, 0);
  ecranOLED.setTextSize(1);                 
  ecranOLED.println(text1);
  ecranOLED.setTextColor(SSD1306_BLACK, SSD1306_WHITE);   // Couleur du texte, et couleur du fond
  ecranOLED.println(text2);
  ecranOLED.setTextColor(SSD1306_WHITE, SSD1306_BLACK);   // Couleur du texte, et couleur du fond
  ecranOLED.println(text3);
  ecranOLED.println(text4);
  ecranOLED.display();    
  delay(1000);
}

// Mesure du flex sensor
void FlexSensor(){
  int ADCflex;
  float Vflex;
  float Rflex;
  ecranOLED.clearDisplay();                                   // Effaçage de l'intégralité du buffer
  ecranOLED.setTextSize(1);                   // Taille des caractères (1:1, puis 2:1, puis 3:1)
  ecranOLED.setCursor(0, 0);
  ecranOLED.setTextColor(SSD1306_WHITE, SSD1306_BLACK);   // Couleur du texte, et couleur du fond
  ecranOLED.println(F("Mesure Flex Sensor:"));
  ecranOLED.display();    
  delay(1000);
  do
  {  
    // Read the ADC, and calculate voltage and resistance from it
    ADCflex = analogRead(flexPin);
    Vflex = ADCflex * VCC / 1024.0;
    Rflex = R_DIV * (VCC / Vflex - 1.0); // Calcul de la résistance du flex
    // Use the calculated resistance to estimate the sensor's bend angle:
    // float angle = map(Rflex, flatResistance, bendResistance, 0, 90.0);
    // Serial.println("Bend: " + String(angle) + " degrees");
    delay(500);
    DisplayAndTransmitter(Rflex,3);
    CheckBoutons();
  }while(!(OK == 1 || OK_TEL == 1));
  //Position=3;
  OK=0;
  //OK_TEL=0;    
  ecranOLED.clearDisplay();                                   // Effaçage de l'intégralité du buffer
  ecranOLED.setCursor(0, 0);
  ecranOLED.setTextSize(1);
  ecranOLED.setTextColor(SSD1306_WHITE, SSD1306_BLACK);   // Couleur du texte, et couleur du fond                 
  ecranOLED.println(text1);
  ecranOLED.println(text2);
  ecranOLED.setTextColor(SSD1306_BLACK, SSD1306_WHITE);
  ecranOLED.println(text3);
  ecranOLED.setTextColor(SSD1306_WHITE, SSD1306_BLACK); 
  ecranOLED.println(text4);
  ecranOLED.display();
  delay(1000);
}

// Transmet la donnée à afficher à l'ordi, à l'écran et au bluetooth
void DisplayAndTransmitter(float VALUE, int choix){
  char ResASCII[10];
  dtostrf(VALUE, 5, 2, ResASCII); //Transforme le float en chaine de caractères
  ecranOLED.clearDisplay();                                   // Effaçage de l'intégralité du buffer
  ecranOLED.setTextSize(1);                   // Taille des caractères (1:1, puis 2:1, puis 3:1)
  ecranOLED.setCursor(0, 0);
  ecranOLED.setTextColor(SSD1306_WHITE, SSD1306_BLACK);   // Couleur du texte, et couleur du fond
  if(choix==1){ecranOLED.println(F("Mesure instantanee :"));}
  else if(choix==2){ecranOLED.println(F("Mesure moyennee :"));}
  else if(choix==3){ecranOLED.println(F("Mesure Flex Sensor :"));dtostrf(VALUE, 5, 0, ResASCII);}
  else if(choix==4){ecranOLED.println(F("Calibration en cours"));}
  ecranOLED.setTextSize(3);                   // Ecris en gros
  ecranOLED.setCursor(0, 30); // Ecris à gauche de l'écran
  ecranOLED.print(ResASCII); // Envoyer sur l'écran la valeur
  mySerial.write(ResASCII); // Envoyer sur le port bluetooth la valeur acquise
  Serial.println(ResASCII); // Afficher sur le port série la valeur de la tension mesuré en bytes
  ecranOLED.display();                            // Transfert le buffer à l'écran
  delay(50);

}

//Calibration basé sur un principe de dichotimie, voir internet. Essaie de se placer au centre de la plage des 1024 valeurs
int Calibration(){
  ecranOLED.clearDisplay();                                   // Effaçage de l'intégralité du buffer
  ecranOLED.setTextSize(1);                   // Taille des caractères (1:1, puis 2:1, puis 3:1)
  ecranOLED.setCursor(0, 0);
  ecranOLED.setTextColor(SSD1306_WHITE, SSD1306_BLACK);   // Couleur du texte, et couleur du fond
  ecranOLED.println(F("Calibration en cours"));
  ecranOLED.display();    
  delay(2000);   
  int Vadc=0;
  int tolerance=40; //Tolerance : 512+-20
  int V_Cible = 512;
  int a = 0;
  int b = 255;
  int ite=0;
  while(abs(Vadc - V_Cible) > tolerance)
  {
    Vadc=0;
    ite++;
    PotPos = (a + b)/2; // Prend le milieu  des 2 valeurs précédentes
    setPotWiper(pot0,int(PotPos));
    for(int i=0;i<3;i++)
    {
      Vadc += analogRead(capteurgraphitePin);
      delay(200);
    }
    Vadc = int(Vadc/3);
    Serial.print(F("Position Pota :"));
    Serial.print(PotPos);
    Serial.print(F(". Valeur lue :"));
    Serial.println(Vadc); // Afficher sur le port série la valeur de la tension mesuré en bytes
    DisplayAndTransmitter(PotPos,4);
    if(Vadc > V_Cible){ // on change le minimum ou le maximum
      a = PotPos;}
    else{
      b = PotPos;}
    if(ite>12){break;}
  }
  Serial.print(F("Finie. Pota en "));
  Serial.println(PotPos); // Afficher sur le port série la valeur de la tension mesuré en bytes
  return PotPos;

}

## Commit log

2025-02-21 Ajout de ma to do liste
2025-03-24 connectique suite
    [Shield.kicad_pcb]
2025-03-25 pcb and mask
    [Shield.kicad_pcb, Shield.kicad_sch]
